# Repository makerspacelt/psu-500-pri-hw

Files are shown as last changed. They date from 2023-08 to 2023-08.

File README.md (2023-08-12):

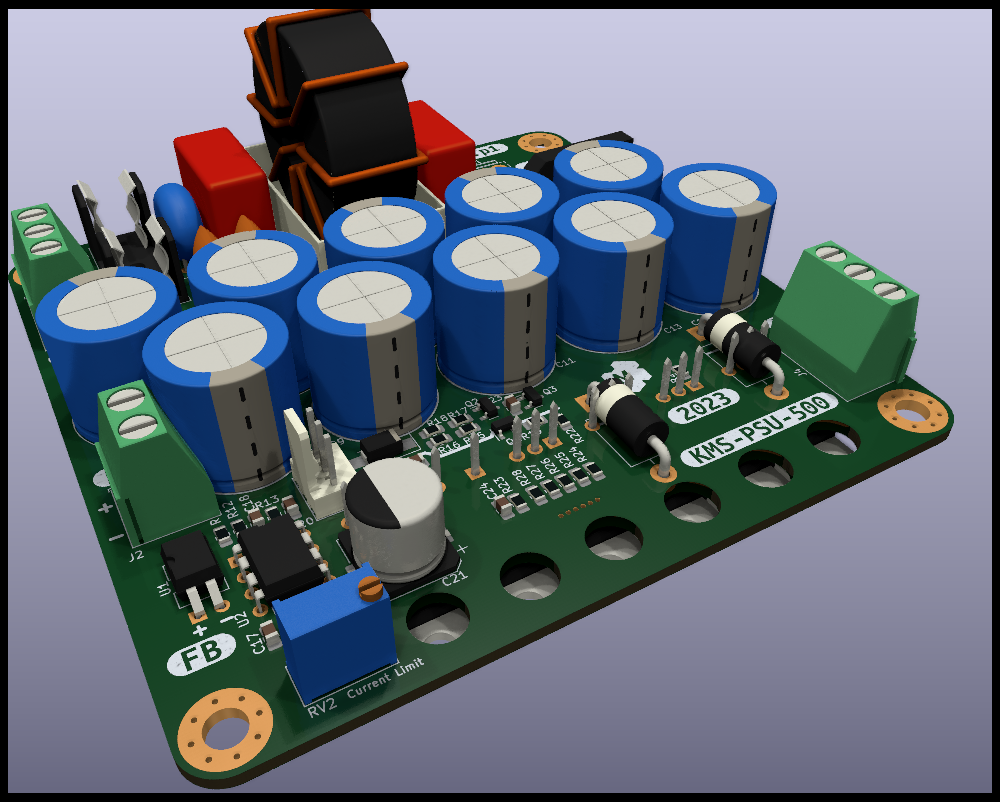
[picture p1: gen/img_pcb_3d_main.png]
PCB 3d main


This is atempt to design a 500W PSU primary side 

Dev NOTE: before commit, run `./kibot.sh` to regenerate documentation, gerbers and other assets.

* [schematics.pdf](gen/schematics.pdf)
* [pcb.pdf with dimensions](gen/pcb.pdf)

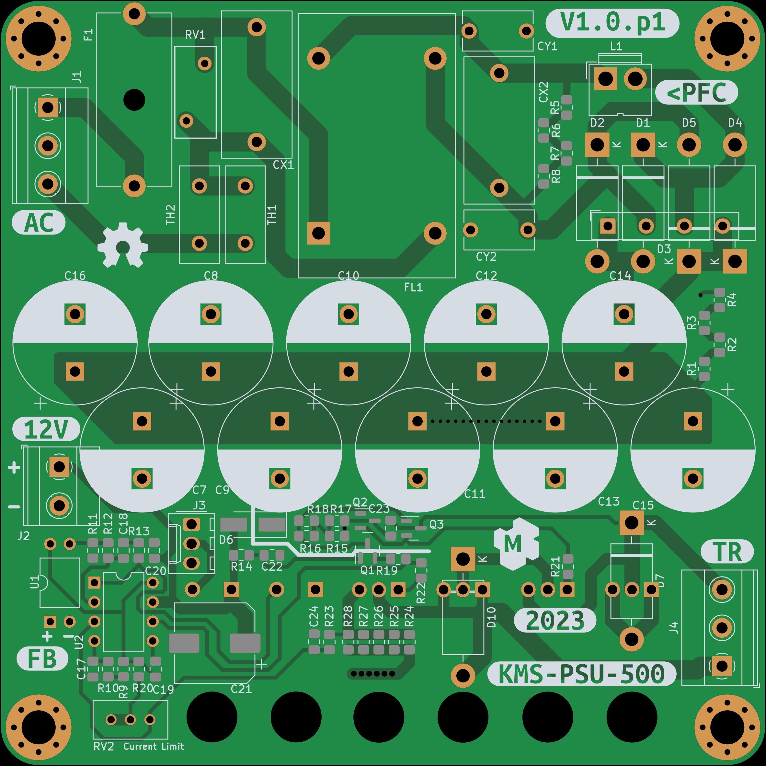
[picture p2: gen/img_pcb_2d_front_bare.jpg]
PCB 2d front bare

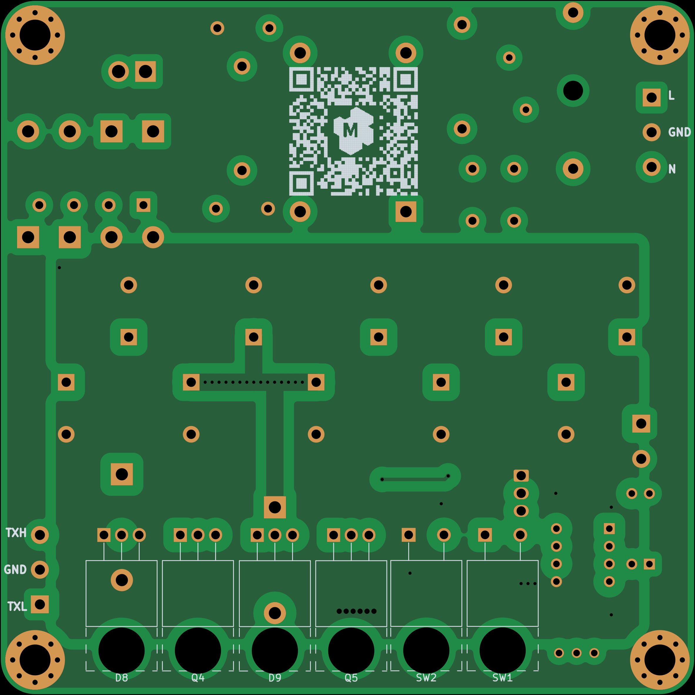
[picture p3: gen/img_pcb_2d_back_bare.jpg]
PCB 2d back bare


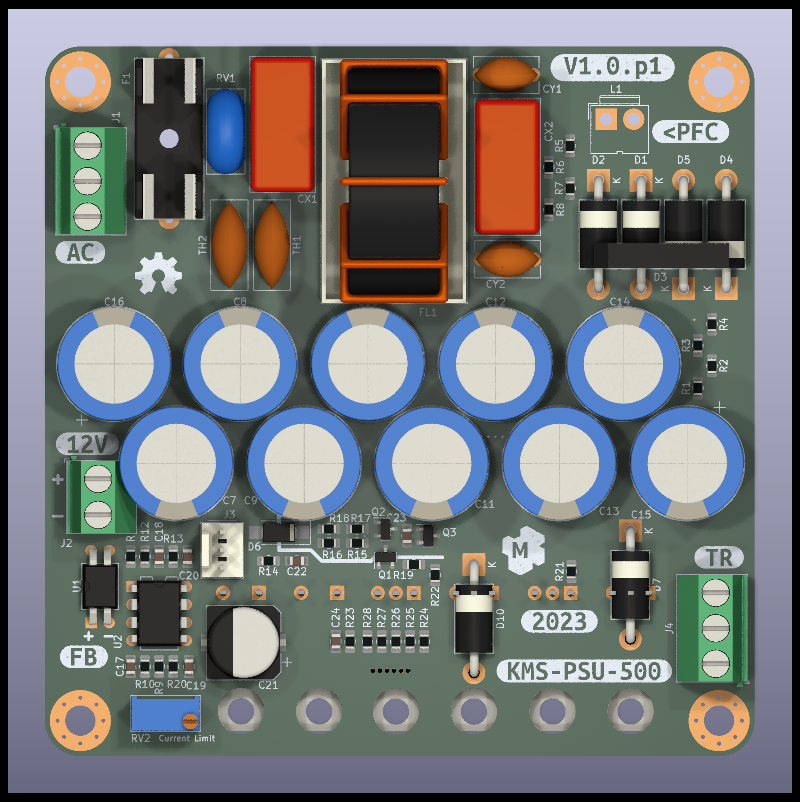
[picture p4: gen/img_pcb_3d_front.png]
PCB 3d front


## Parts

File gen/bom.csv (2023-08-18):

Row | Description | Part | References | Value | Footprint | Quantity Per PCB | Status | Datasheet | jlc-part-type | LCSC# | Value2
1 | Unpolarized capacitor | C | C24 | 100p | C_0805_2012Metric_Pad1.18x1.45mm_HandSolder | 1 |  | ~
2 | Unpolarized capacitor | C | C17 | 1n | C_0805_2012Metric_Pad1.18x1.45mm_HandSolder | 1 |  | ~
3 | Unpolarized capacitor | C | C18 | 10n | C_0805_2012Metric_Pad1.18x1.45mm_HandSolder | 1 |  | ~
4 | Unpolarized capacitor | C | C20,C22 | 100n | C_0805_2012Metric_Pad1.18x1.45mm_HandSolder | 2 |  | ~
5 | Unpolarized capacitor | C | C23 | 1u | C_0805_2012Metric_Pad1.18x1.45mm_HandSolder | 1 |  | ~ |  |  | 16V
6 | Unpolarized capacitor | C | C19 | 10u | C_0805_2012Metric_Pad1.18x1.45mm_HandSolder | 1 |  | ~ |  |  | 10v
7 | Polarized capacitor | C_Polarized | C7,C8,C9,C10,C11,C12,C13,C14,C15,C16 | 47u | CP_Radial_D16.0mm_P7.50mm | 10 |  | ~ |  |  | 400v
8 | Polarized capacitor | C_Polarized | C21 | 100u | CP_Elec_10x10 | 1 |  | ~ |  |  | 16v
9 | Polarized capacitor | C_Polarized | C1,C2 | 220u | CP_Radial_D30.0mm_P10.00mm_SnapIn | 2 |  | ~ |  |  | 400v
10 | Polarized capacitor | C_Polarized | C3,C4,C5,C6 | 470u | CP_Radial_D24.0mm_P10.00mm_SnapIn | 4 |  | ~ |  |  | 200v
11 | Unpolarized capacitor | C | CX1,CX2 | 470n | C_Rect_L19.0mm_W9.0mm_P15.00mm_MKS4 | 2 |  | https://datasheet.lcsc.com/lcsc/C5454415.pdf |  | C5454415 | 250V~
12 | Unpolarized capacitor | C | CY1,CY2 | 2n2 | C_Disc_D9.0mm_W5.0mm_P7.50mm | 2 |  | https://datasheet.lcsc.com/lcsc/C5355118.pdf |  | C5355118 | 250V~
13 | Silicon Bridge Rectifier, 40V Vrms, 1.5A If, pins=-AA+, SIL-package | B40C2300-1500A | D3 | GBU1010 | Diode_Bridge_19.0x3.5x10.0mm_P5.0mm | 1 |  | https://datasheet.lcsc.com/lcsc/2208121800_SEP-GBU1010_C5127096.pdf |  | C5127096
14 | Dual diode, common anode on pin 1 | D_Dual_CommonCathode_AKA_Parallel | D8,D9 | MURF1040GCT | TO-220-3_Horizontal_TabUp | 2 |  | https://datasheet.lcsc.com/lcsc/2205111516_DIYI-Elec-Tech-MURF1040GCT-H_C2995510.pdf |  | C2995510
15 | 1000V 3A Soft Recovery Ultrafast Rectifier Diode, DO-201AD | UF5408 | D6 | S2M | D_SMA_Handsoldering | 1 |  | https://datasheet.lcsc.com/lcsc/1811101212_Shandong-Jingdao-Microelectronics-S2M_C116114.pdf |  |  | 400V
16 | 1000V 3A General Purpose Rectifier Diode, DO-201AD | 1N5408 | D7,D10 | UF5408 | D_DO-201AD_P15.24mm_Horizontal | 2 |  | https://datasheet.lcsc.com/lcsc/1912111437_SUNMATE-Elec-UF5408_C424502.pdf
17 | 1000V 3A General Purpose Rectifier Diode, DO-201AD | 1N5408 | D1,D2,D4,D5 | ~ | D_DO-201AD_P15.24mm_Horizontal | 4 |  | ~
18 | Fuse | Fuse | F1 | 5A | Fuseholder_Cylinder-5x20mm_Schurter_0031_8201_Horizontal_Open | 1 |  | https://datasheet.lcsc.com/lcsc/C717030.pdf |  | C717030
19 | EMI 2-inductor common mode filter | Filter_EMI_CommonMode | FL1 | EMI | L_CommonMode_Toroid_Vertical_L34.3mm_W20.3mm_Px15.24mm_Py22.86mm_Bourns_8100 | 1 |  | https://datasheet.lcsc.com/lcsc/2201121530_PROD-Tech-PDUUAT105-202MLN_C2932158.pdf |  | C2932158
20 | Generic screw terminal, single row, 01x02, script generated (kicad-library-utils/schlib/autogen/connector/) | Screw_Terminal_01x02 | J2 | 12V | TerminalBlock_Phoenix_MKDS-1,5-2-5.08_1x02_P5.08mm_Horizontal | 1 |  | ~
21 | Generic screw terminal, single row, 01x03, script generated (kicad-library-utils/schlib/autogen/connector/) | Screw_Terminal_01x03 | J1,J4 | AC | TerminalBlock_Phoenix_MKDS-1,5-3_1x03_P5.00mm_Horizontal | 2 |  | ~
22 | Generic connector, single row, 01x03, script generated (kicad-library-utils/schlib/autogen/connector/) | Conn_01x03 | J3 | FAN | Molex_KK-254_AE-6410-03A_1x03_P2.54mm_Vertical | 1 |  | ~
23 | Inductor with iron core | L_Iron | L1 | PFC | JWT_A3963_1x02_P3.96mm_Vertical | 1 |  | ~
24 | Compact AC/DC board mount power module 3W 5V | HLK-PM01 | PS1 | PSU 12V 1A | Converter_ACDC_HiLink_HLK-PMxx | 1 |  | http://www.hlktech.net/product_detail.php?ProId=54
25 | NPN transistor, base/emitter/collector | Q_NPN_BEC | Q1 | 13001 | SOT-23 | 1 |  | https://datasheet.lcsc.com/lcsc/2212161630_HXY-MOSFET-13001_C5261071.pdf |  | C5261071 | 400V
26 | 10A Id, 400V Vds, N-Channel Power MOSFET, 500mOhm Rds, TO-220AB | IRF740 | Q4,Q5 | IRF740 | TO-220-3_Horizontal_TabUp | 2 |  | https://datasheet.lcsc.com/lcsc/2203231030_Minos-IRF740_C2980280.pdf |  | C2980280
27 | NPN transistor, base/emitter/collector | Q_NPN_BEC | Q2 | S8050 | SOT-23 | 1 |  | https://datasheet.lcsc.com/lcsc/2304140030_Jiangsu-Changjing-Electronics-Technology-Co---Ltd--S8050_C105433.pdf
28 | PNP transistor, base/emitter/collector | Q_PNP_BEC | Q3 | S8550 | SOT-23 | 1 |  | https://datasheet.lcsc.com/lcsc/2205061000_Guangdong-Hottech-S8550_C181159.pdf
29 | Resistor | R | R24,R25,R26,R27,R28 | 0R1 | R_0805_2012Metric_Pad1.20x1.40mm_HandSolder | 5 |  | ~
30 | Resistor | R | R19,R21,R22 | 10 | R_0805_2012Metric_Pad1.20x1.40mm_HandSolder | 3 |  | ~
31 | Resistor | R | R11,R15,R16,R17,R18,R23 | 1k | R_0805_2012Metric_Pad1.20x1.40mm_HandSolder | 6 |  | ~
32 | Resistor | R | R10 | 2k2 | R_0805_2012Metric_Pad1.20x1.40mm_HandSolder | 1 |  | ~
33 | Resistor | R | R12,R20 | 4k7 | R_0805_2012Metric_Pad1.20x1.40mm_HandSolder | 2 |  | ~
34 | Resistor | R | R13,R14 | 10k | R_0805_2012Metric_Pad1.20x1.40mm_HandSolder | 2 |  | ~
35 | Resistor | R | R9 | 15k | R_0805_2012Metric_Pad1.20x1.40mm_HandSolder | 1 |  | ~
36 | Resistor | R | R1,R2,R3,R4,R5,R6,R7,R8 | 220k | R_0805_2012Metric_Pad1.20x1.40mm_HandSolder | 8 |  | ~
37 | Trim-potentiometer | R_Potentiometer_Trim | RV2 | 4k7 | Potentiometer_Bourns_3296W_Vertical | 1 |  | ~
38 | Voltage dependent resistor | Varistor | RV1 | 10D431K | RV_Disc_D12mm_W5.4mm_P7.5mm | 1 |  | https://datasheet.lcsc.com/lcsc/2304140030_COV-10D431K_C317794.pdf |  | C317794
39 | Single Pole Single Throw (SPST) switch, temperature dependent | SW_SPST_Temperature | SW1 | 50C NC | TO-220-2_Horizontal_TabUp | 1 |  | ~
40 | Single Pole Single Throw (SPST) switch, temperature dependent | SW_SPST_Temperature | SW2 | 85C | TO-220-2_Horizontal_TabUp | 1 |  | ~
41 | Flash symbol, small | SYM_Flash_Small | SYM1 | SYM_Flash_Small | qr | 1 |  | ~
42 | Temperature dependent resistor, negative temperature coefficient | Thermistor_NTC | TH1,TH2 | 5D-15 | C_Disc_D12.5mm_W5.0mm_P7.50mm | 2 |  | https://datasheet.lcsc.com/lcsc/C2839620.pdf |  | C2839620
43 | DC Optocoupler, Vce 35V, CTR 50%, DIP-4 | LTV-817M | U1 | LTV-817M | DIP-4_W10.16mm | 1 |  | http://www.us.liteon.com/downloads/LTV-817-827-847.PDF |  | C109226
44 | Current-Mode PWM Controllers, 50% Duty Cycle, 8.4V/7.6V UVLO, PDIP-8 | UC3845_DIP8 | U2 | UC3845B | DIP-8_W7.62mm | 1 |  | https://datasheet.lcsc.com/lcsc/2007031829_UMW-Youtai-Semiconductor-Co---Ltd--UC3845B_C347460.pdf |  | C347460

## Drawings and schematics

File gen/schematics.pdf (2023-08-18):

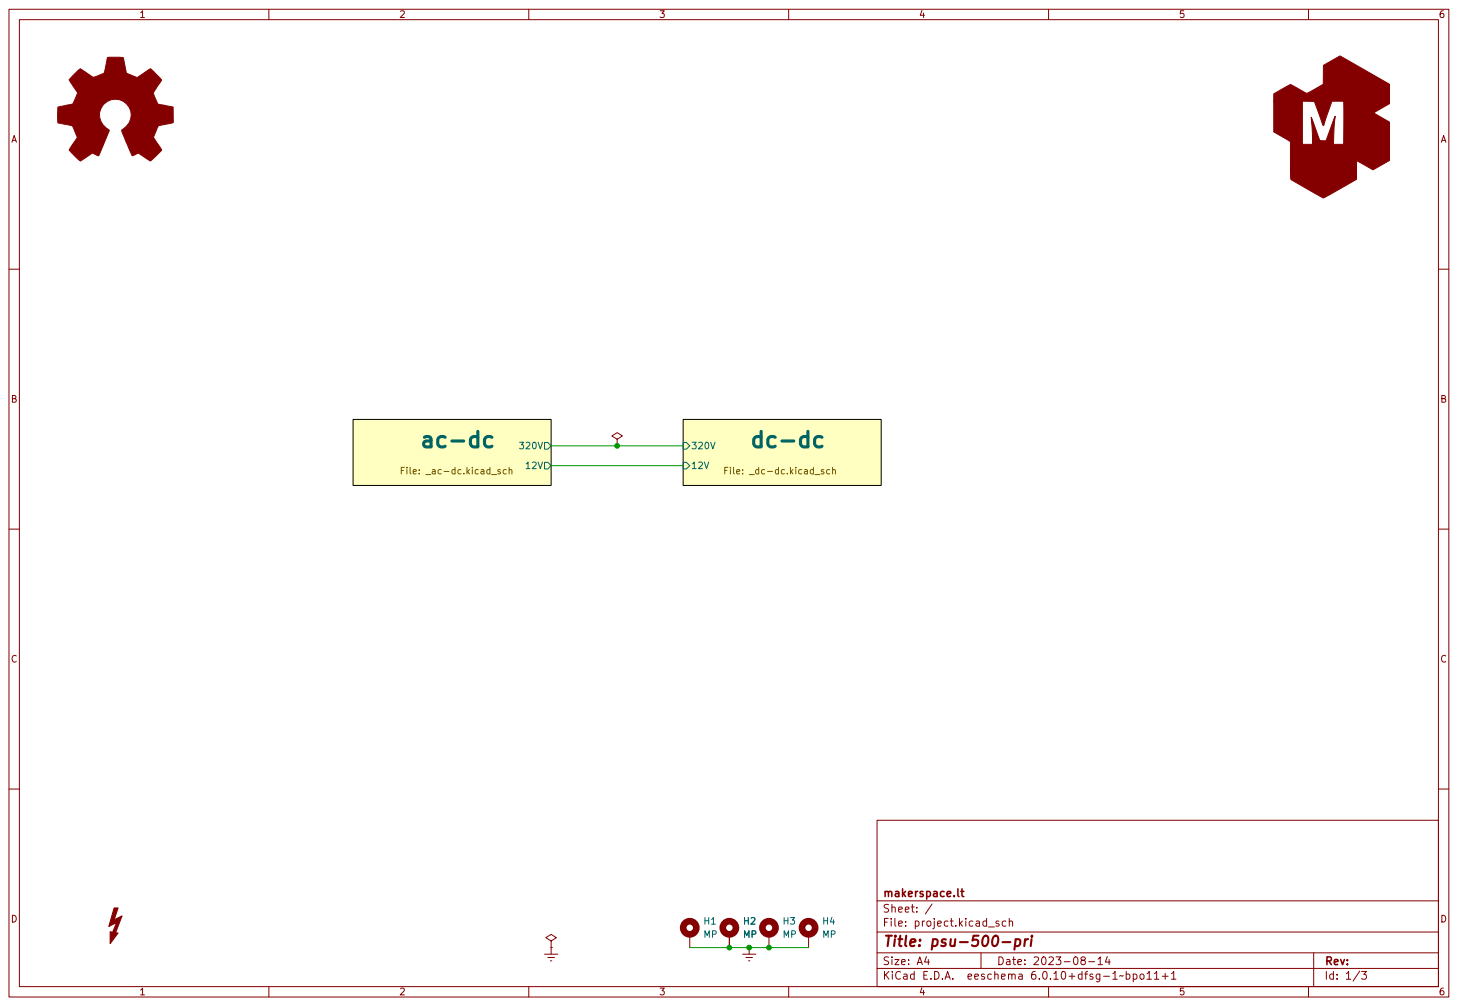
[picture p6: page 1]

File: project.kicad_sch Sheet: / makerspace.lt

Id: 1/3 Title: psu-500-pri

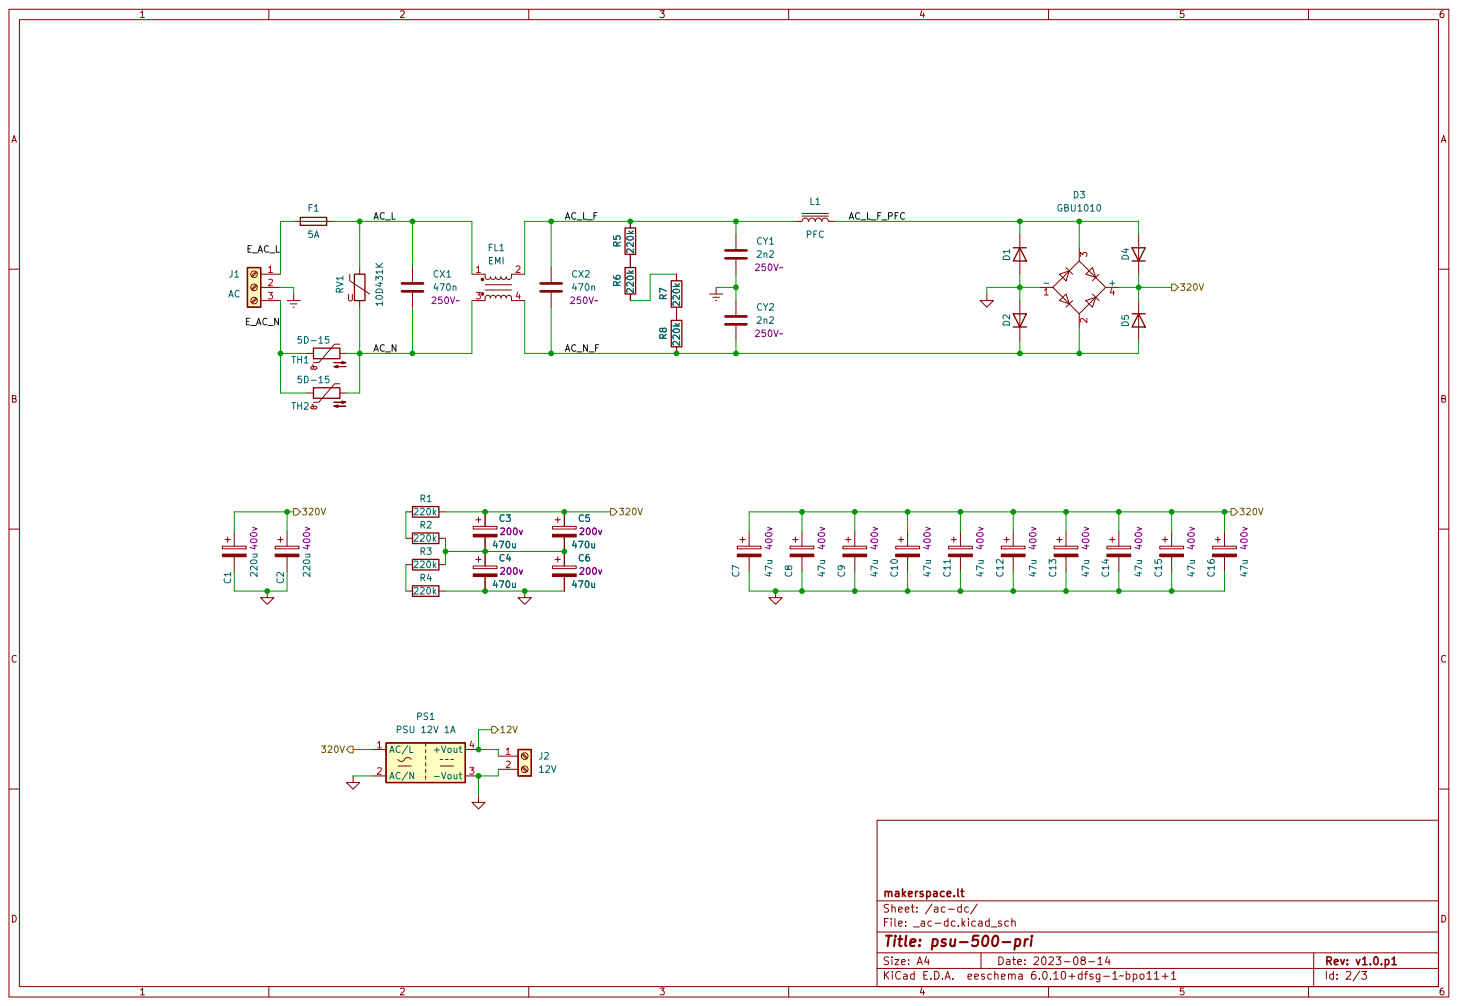
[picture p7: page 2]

File: _ac-dc.kicad_sch Sheet: /ac-dc/ makerspace.lt R1

Id: 2/3 Title: psu-500-pri

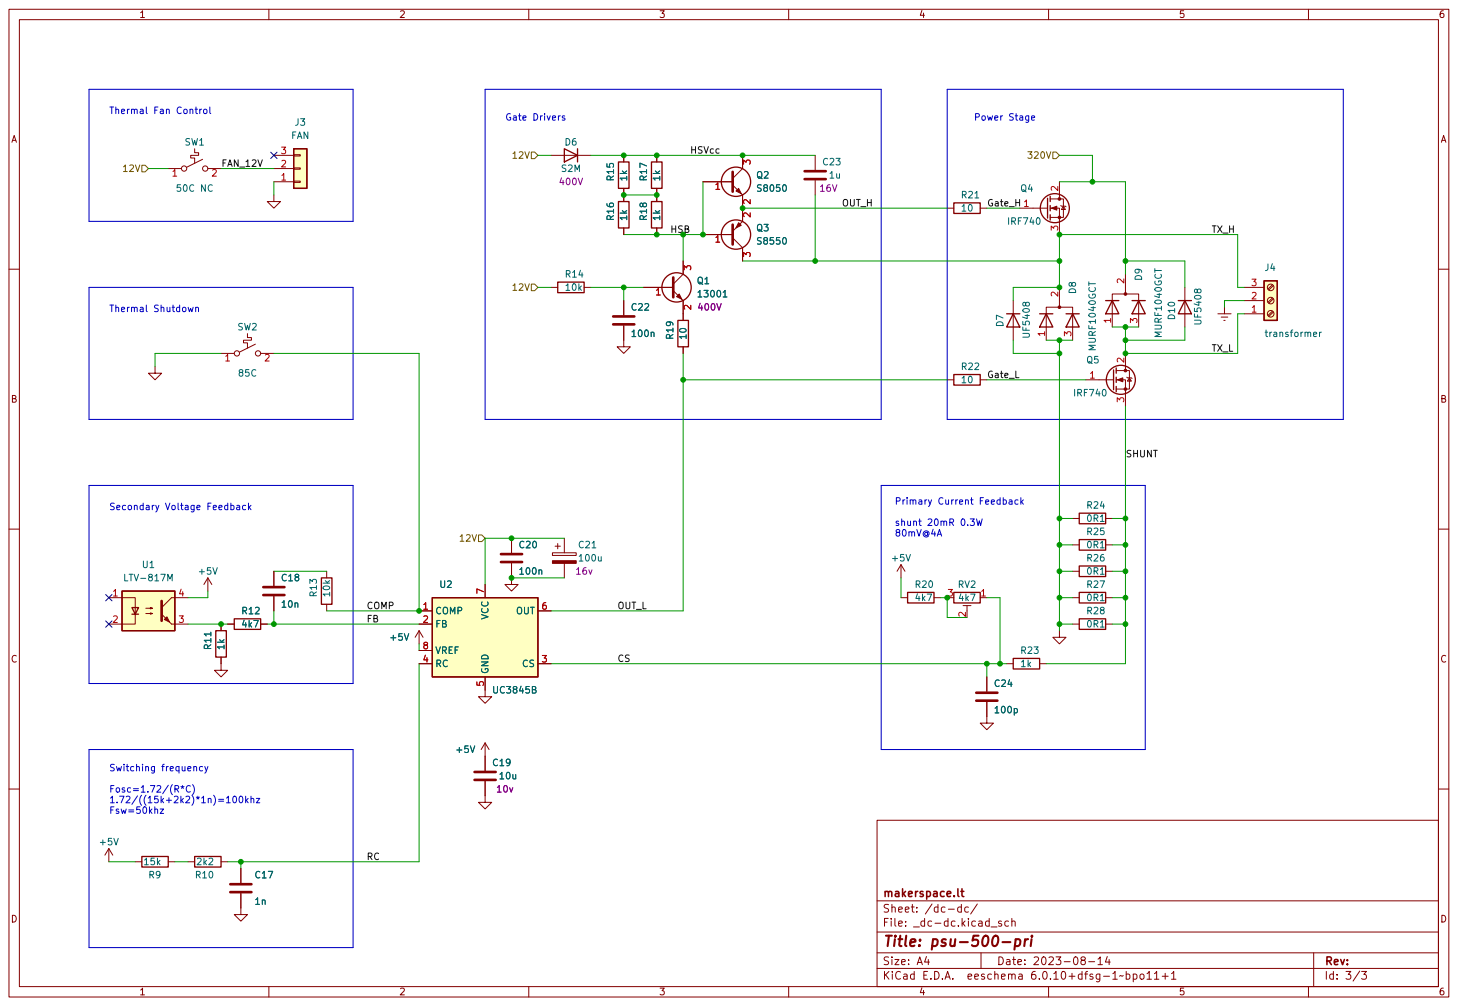
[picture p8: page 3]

File: _dc-dc.kicad_sch Sheet: /dc-dc/ makerspace.lt

Id: 3/3 Title: psu-500-pri

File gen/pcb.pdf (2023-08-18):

100 mm

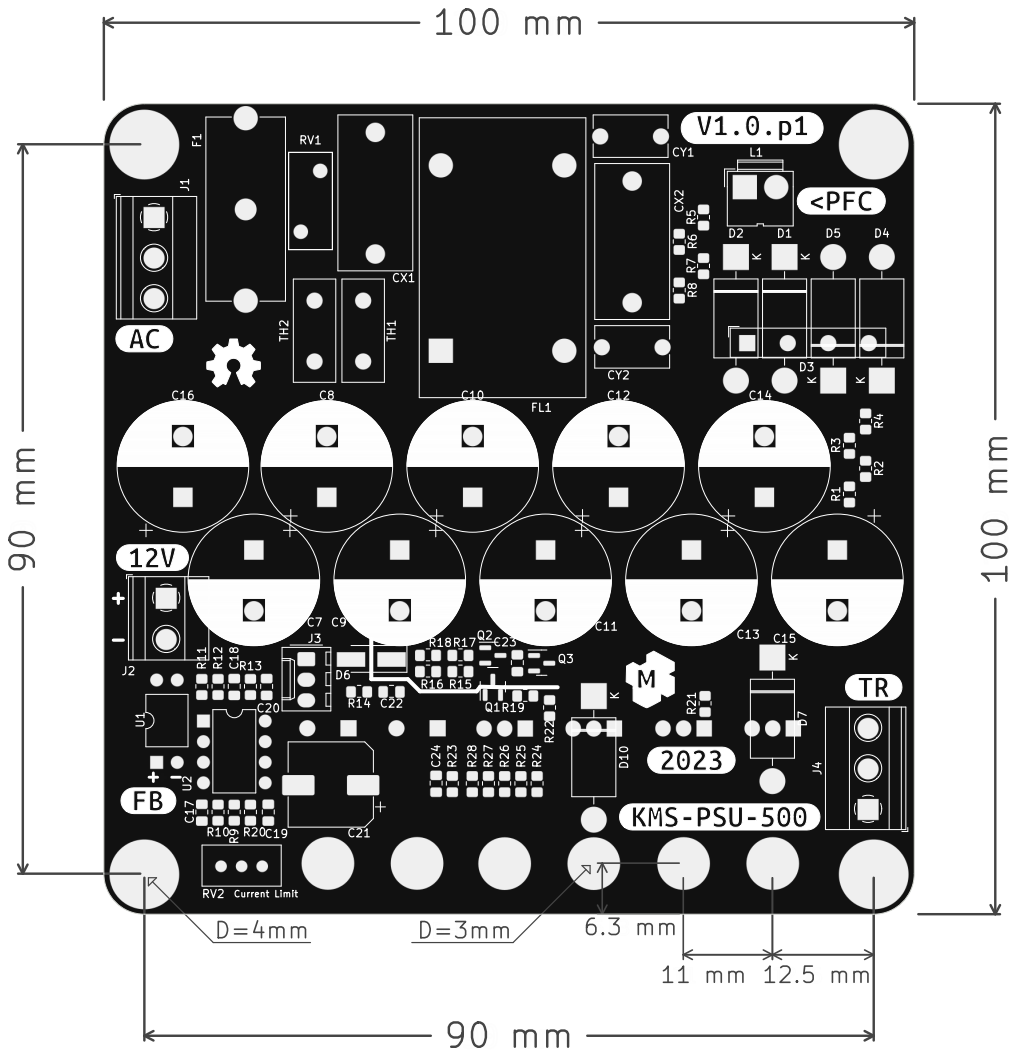
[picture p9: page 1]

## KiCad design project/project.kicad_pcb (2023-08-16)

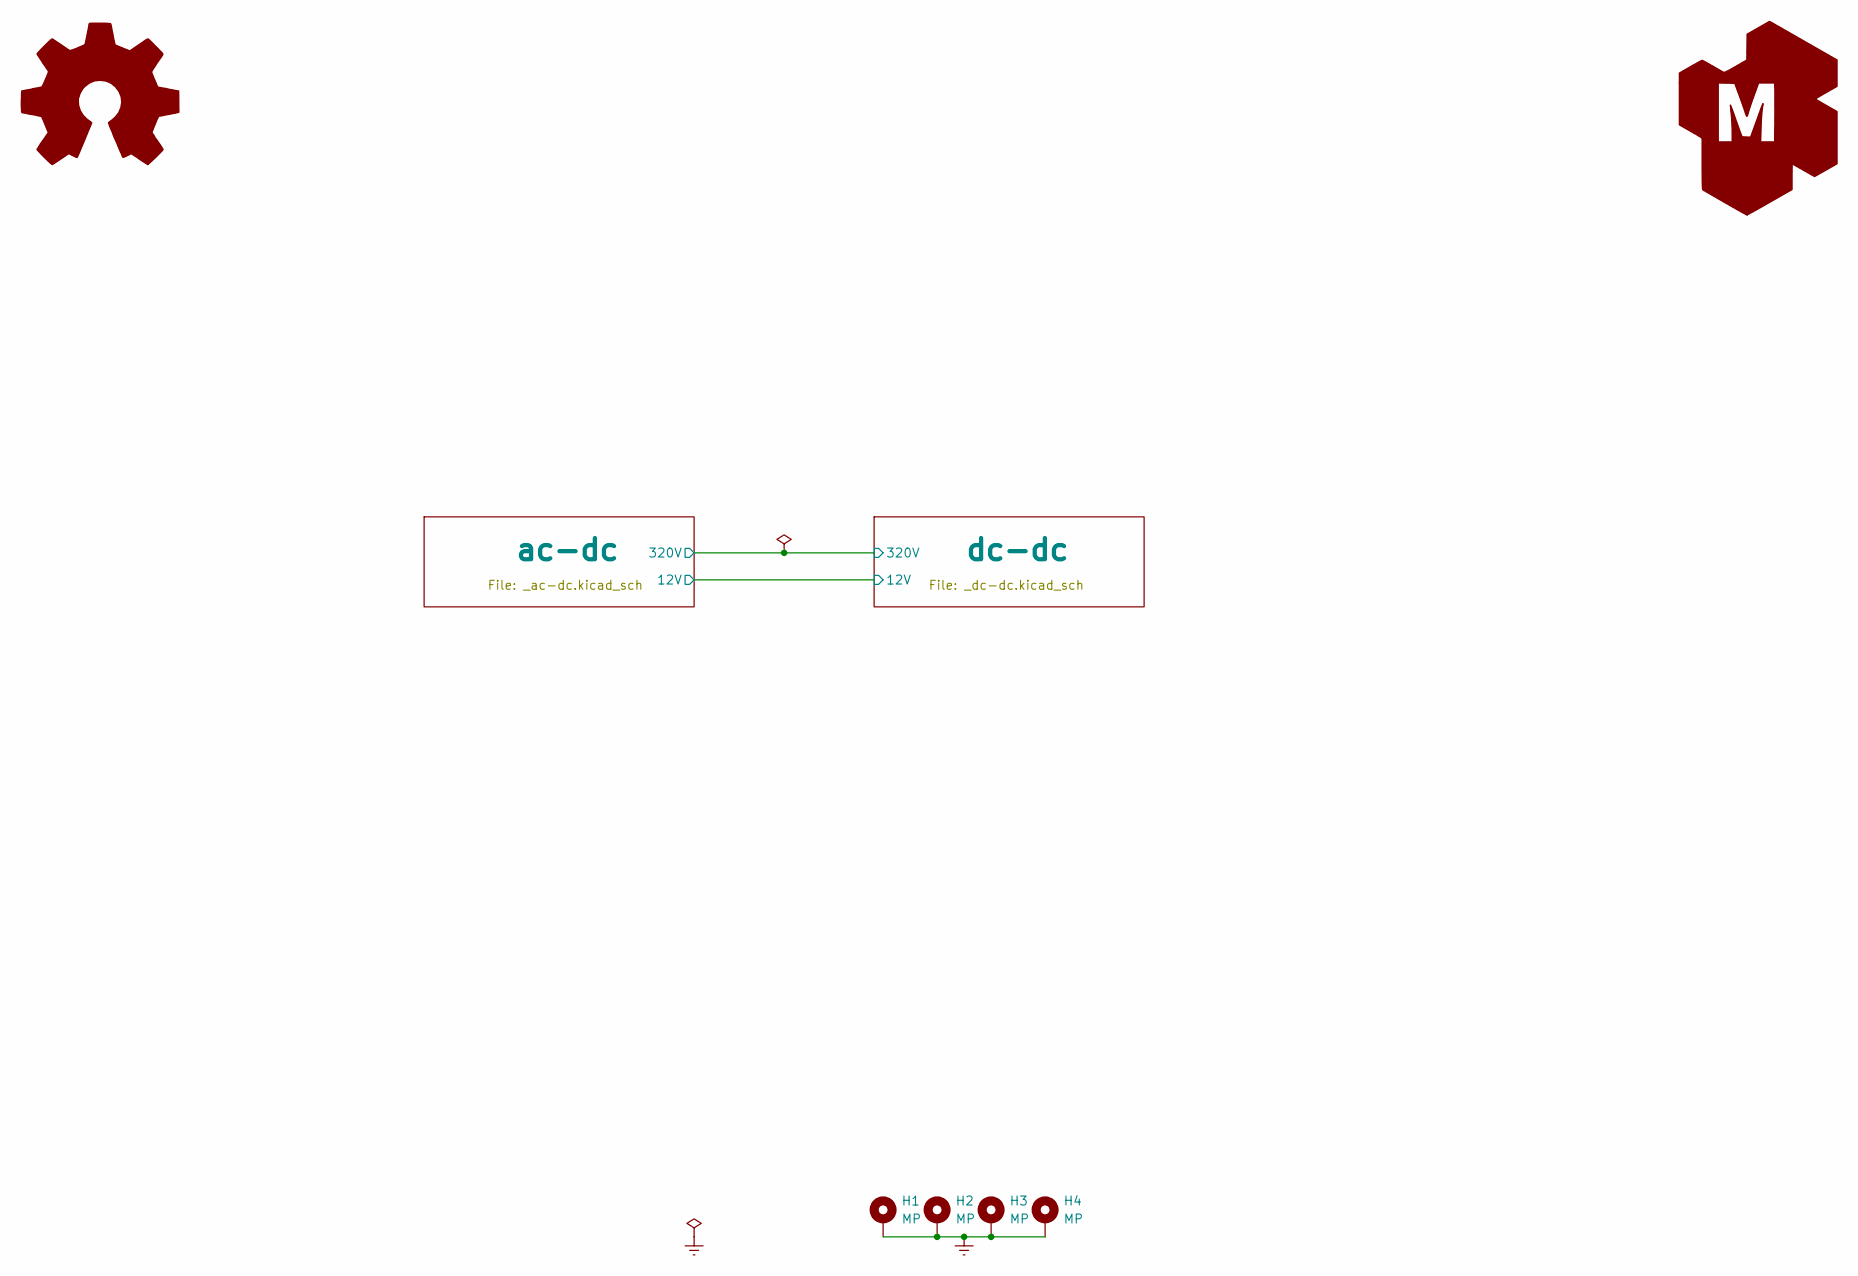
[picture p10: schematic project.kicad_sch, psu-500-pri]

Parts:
G1: Logo_Open_Hardware_Large; OSHW-Symbol_6.7x6mm_SilkScreen
G2: LOGO_KMS; logo_kms_small_silkscreen
H1, H2, H3, H4: MP; MountingHole_4.3mm_M4_Pad_Via

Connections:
Earth: H1.1, H2.1, H3.1, H4.1; also elsewhere on the board

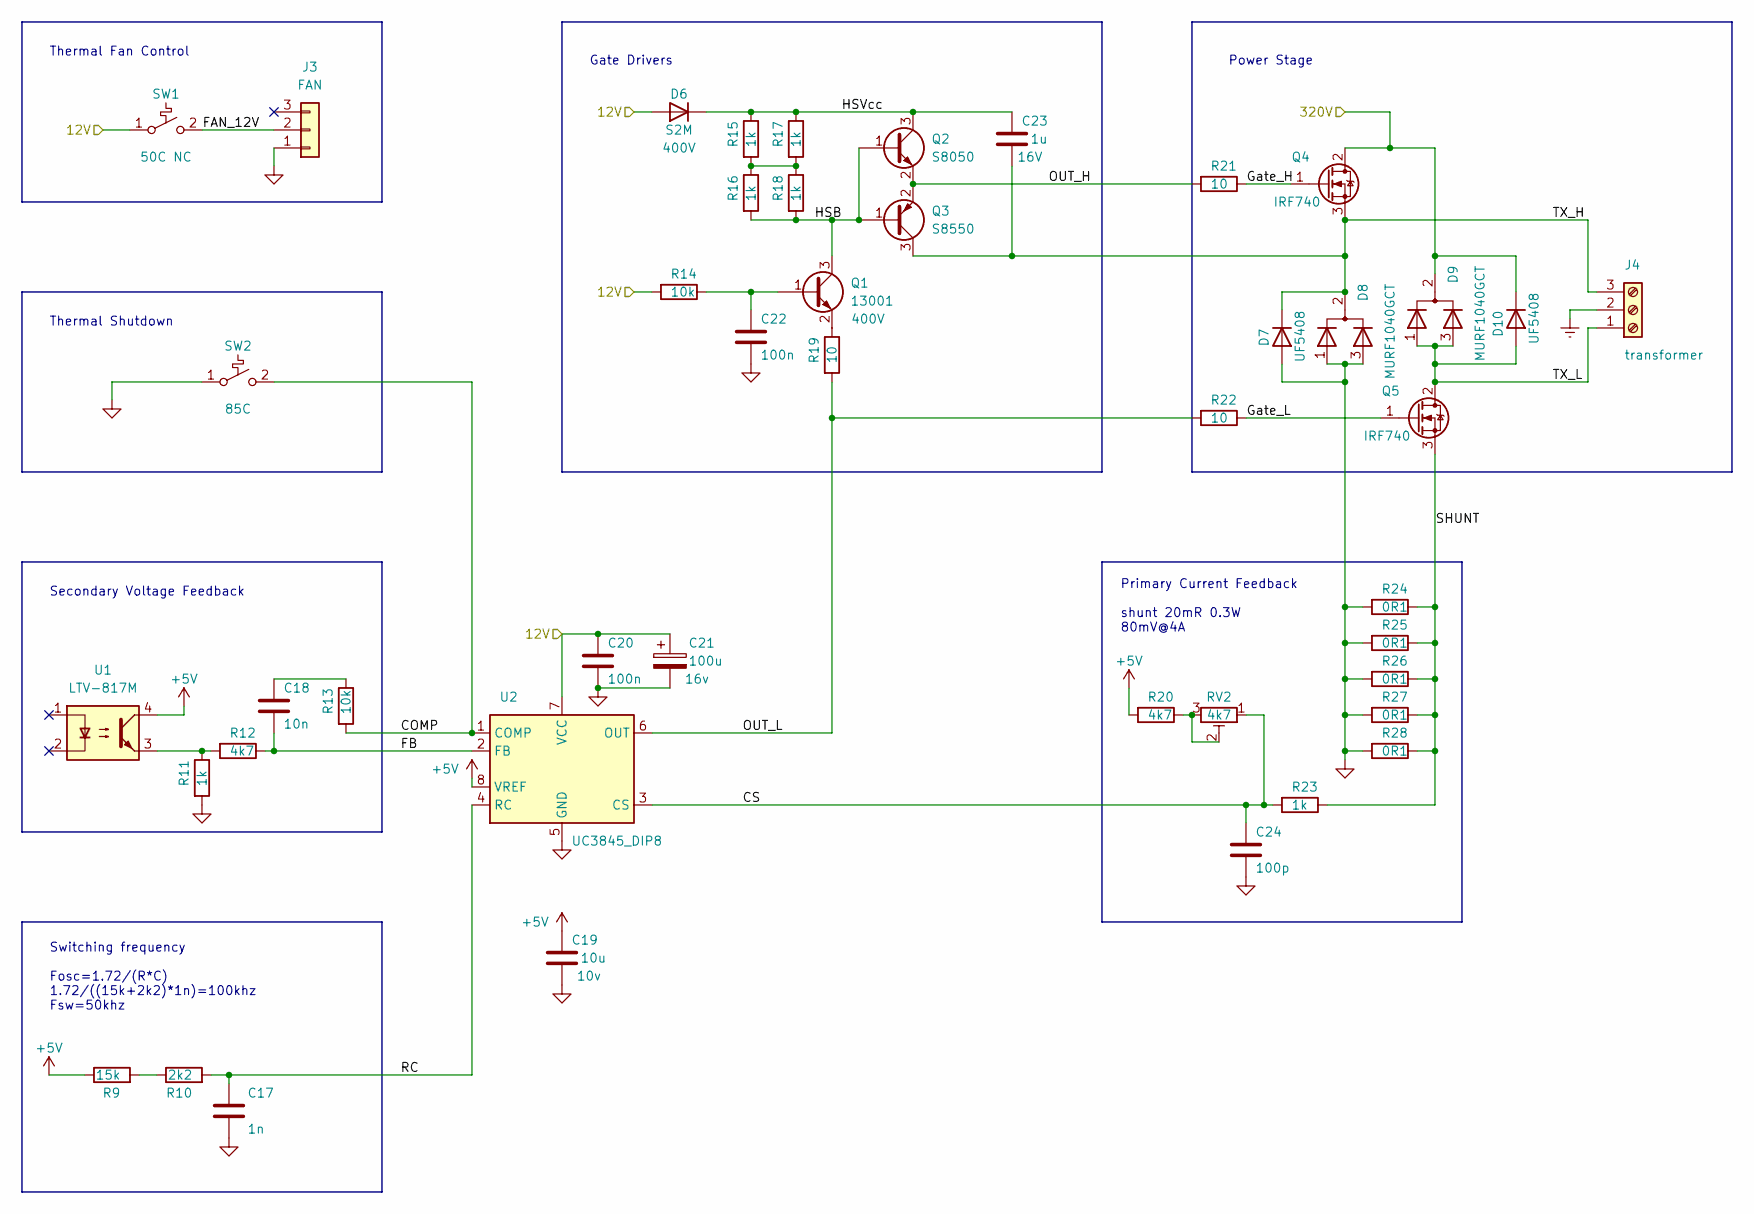
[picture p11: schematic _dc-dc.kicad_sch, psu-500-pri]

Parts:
C17: 1n; C_0805_2012Metric_Pad1.18x1.45mm_HandSolder
C18: 10n; C_0805_2012Metric_Pad1.18x1.45mm_HandSolder
C19: 10u; C_0805_2012Metric_Pad1.18x1.45mm_HandSolder
C20, C22: 100n; C_0805_2012Metric_Pad1.18x1.45mm_HandSolder
C21: 100u; CP_Elec_10x10
C23: 1u; C_0805_2012Metric_Pad1.18x1.45mm_HandSolder
C24: 100p; C_0805_2012Metric_Pad1.18x1.45mm_HandSolder
D6: S2M; D_SMA_Handsoldering
D7, D10: UF5408; D_DO-201AD_P15.24mm_Horizontal
D8, D9: MURF1040GCT; TO-220-3_Horizontal_TabUp; LCSC# C2995510
J3: FAN; Molex_KK-254_AE-6410-03A_1x03_P2.54mm_Vertical
J4: transformer; TerminalBlock_Phoenix_MKDS-1,5-3_1x03_P5.00mm_Horizontal
Q1: 13001; SOT-23; LCSC# C5261071
Q2: S8050; SOT-23
Q3: S8550; SOT-23
Q4, Q5: IRF740; TO-220-3_Horizontal_TabUp
R9: 15k; R_0805_2012Metric_Pad1.20x1.40mm_HandSolder
R10: 2k2; R_0805_2012Metric_Pad1.20x1.40mm_HandSolder
R11, R15, R16, R17, R18, R23: 1k; R_0805_2012Metric_Pad1.20x1.40mm_HandSolder
R12, R20: 4k7; R_0805_2012Metric_Pad1.20x1.40mm_HandSolder
R13, R14: 10k; R_0805_2012Metric_Pad1.20x1.40mm_HandSolder
R19, R21, R22: 10; R_0805_2012Metric_Pad1.20x1.40mm_HandSolder
R24, R25, R26, R27, R28: 0R1; R_0805_2012Metric_Pad1.20x1.40mm_HandSolder
RV2: 4k7; Potentiometer_Bourns_3296W_Vertical
SW1: 50C NC; TO-220-2_Horizontal_TabUp
SW2: 85C; TO-220-2_Horizontal_TabUp
U1: LTV-817M; DIP-4_W10.16mm; LCSC# C109226
U2: UC3845_DIP8; DIP-8_W7.62mm

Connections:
+5V: C19.1, R9.1, R20.2, U1.4, U2.8 (VREF)
/ac-dc/12V: C20.1, C21.1, D6.2 (A), R14.2, SW1.1 (A), U2.7 (VCC); also elsewhere on the board
/ac-dc/320V: D9.2 (A), D10.1 (K), Q4.2 (D); also elsewhere on the board
/dc-dc/COMP: R13.2, SW2.2 (B), U2.1 (COMP)
/dc-dc/CS: C24.1, R23.2, RV2.1, U2.3 (CS)
/dc-dc/FAN_12V: J3.2, SW1.2 (B)
/dc-dc/FB: C18.2, R12.1, U2.2 (FB)
/dc-dc/Gate_H: Q4.1 (G), R21.1
/dc-dc/Gate_L: Q5.1 (G), R22.1
/dc-dc/HSB: Q1.3 (C), Q2.1 (B), Q3.1 (B), R16.2, R18.2
/dc-dc/HSVcc: C23.1, D6.1 (K), Q2.3 (C), R15.1, R17.1
/dc-dc/OUT_H: Q2.2 (E), Q3.2 (E), R21.2
/dc-dc/OUT_L: R19.2, R22.2, U2.6 (OUT)
/dc-dc/RC: C17.1, R10.2, U2.4 (RC)
/dc-dc/SHUNT: Q5.3 (S), R23.1, R24.1, R25.1, R26.1, R27.1, R28.1
/dc-dc/TX_H: C23.2, D7.1 (K), D8.2 (A), J4.3, Q3.3 (C), Q4.3 (S)
/dc-dc/TX_L: D9.1 (K), D9.3 (K), D10.2 (A), J4.1, Q5.2 (D)
Earth: J4.2; also elsewhere on the board
GND: C17.2, C19.2, C20.2, C21.2, C22.2, C24.2, D7.2 (A), D8.1 (K), D8.3 (K), J3.1, R11.2, R24.2, R25.2, R26.2, R27.2, R28.2, SW2.1 (A), U2.5 (GND); also elsewhere on the board
unnamed: C18.1, R13.1
unnamed: C22.1, Q1.1 (B), R14.1
unnamed: Q1.2 (E), R19.1
unnamed: R9.2, R10.1
unnamed: R11.1, R12.2, U1.3
unnamed: R15.2, R16.1, R17.2, R18.1
unnamed: R20.1, RV2.2, RV2.3

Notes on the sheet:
Switching frequency Fosc=1.72/(R*C) 1.72/((15k+2k2)*1n)=100khz Fsw=50khz
Primary Current Feedback shunt 20mR 0.3W 80mV@4A
Gate Drivers
Thermal Fan Control
Thermal Shutdown
Secondary Voltage Feedback
Power Stage

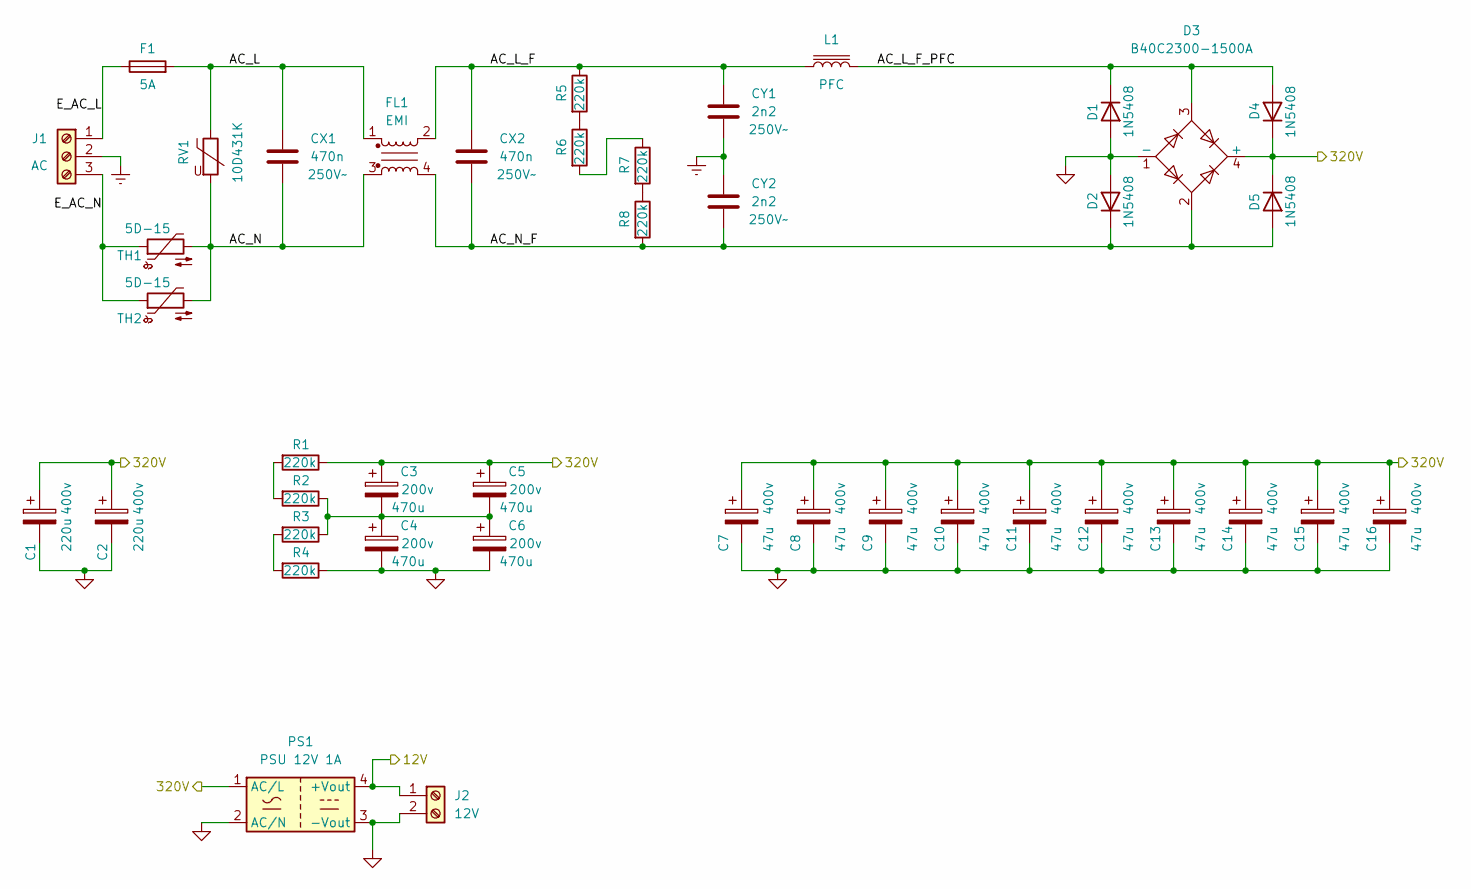
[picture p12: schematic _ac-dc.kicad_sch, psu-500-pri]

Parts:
C1, C2: 220u; CP_Radial_D30.0mm_P10.00mm_SnapIn
C3, C4, C5, C6: 470u; CP_Radial_D24.0mm_P10.00mm_SnapIn
C7, C8, C9, C10, C11, C12, C13, C14, C15, C16: 47u; CP_Radial_D16.0mm_P7.50mm
CX1, CX2: 470n; C_Rect_L19.0mm_W9.0mm_P15.00mm_MKS4
CY1, CY2: 2n2; C_Disc_D9.0mm_W5.0mm_P7.50mm
D1, D2, D4, D5: 1N5408; D_DO-201AD_P15.24mm_Horizontal
D3: B40C2300-1500A; Diode_Bridge_19.0x3.5x10.0mm_P5.0mm
F1: 5A; Fuseholder_Cylinder-5x20mm_Schurter_0031_8201_Horizontal_Op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
FL1: EMI; L_CommonMode_Toroid_Vertical_L34.3mm_W20.3mm_Px15.24mm_Py22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
J1: AC; TerminalBlock_Phoenix_MKDS-1,5-3_1x03_P5.00mm_Horizontal
J2: 12V; TerminalBlock_Phoenix_MKDS-1,5-2-5.08_1x02_P5.08mm_Horizont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
L1: PFC; JWT_A3963_1x02_P3.96mm_Vertical
PS1: PSU 12V 1A; Converter_ACDC_HiLink_HLK-PMxx
R1, R2, R3, R4, R5, R6, R7, R8: 220k; R_0805_2012Metric_Pad1.20x1.40mm_HandSolder
RV1: 10D431K; RV_Disc_D12mm_W5.4mm_P7.5mm; LCSC# C317794
TH1, TH2: 5D-15; C_Disc_D12.5mm_W5.0mm_P7.50mm

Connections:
/ac-dc/12V: J2.1, PS1.4 (+Vout); also elsewhere on the board
/ac-dc/320V: C1.1, C2.1, C3.1, C5.1, C7.1, C8.1, C9.1, C10.1, C11.1, C12.1, C13.1, C14.1, C15.1, C16.1, D3.4 (+), D4.1 (K), D5.1 (K), PS1.1 (AC/L), R1.1; also elsewhere on the board
/ac-dc/AC_L: CX1.1, F1.2, FL1.1, RV1.1
/ac-dc/AC_L_F: CX2.1, CY1.1, FL1.2, L1.1, R5.1
/ac-dc/AC_L_F_PFC: D1.1 (K), D3.3, D4.2 (A), L1.2
/ac-dc/AC_N: CX1.2, FL1.3, RV1.2, TH1.2, TH2.2
/ac-dc/AC_N_F: CX2.2, CY2.2, D2.1 (K), D3.2, D5.2 (A), FL1.4, R8.2
/ac-dc/E_AC_L: F1.1, J1.1
/ac-dc/E_AC_N: J1.3, TH1.1, TH2.1
Earth: CY1.2, CY2.1, J1.2; also elsewhere on the board
GND: C1.2, C2.2, C4.2, C6.2, C7.2, C8.2, C9.2, C10.2, C11.2, C12.2, C13.2, C14.2, C15.2, C16.2, D1.2 (A), D2.2 (A), D3.1 (-), J2.2, PS1.2 (AC/N), PS1.3 (-Vout), R4.1; also elsewhere on the board
unnamed: C3.2, C4.1, C5.2, C6.1, R2.1, R3.1
unnamed: R1.2, R2.2
unnamed: R3.2, R4.2
unnamed: R5.2, R6.1
unnamed: R6.2, R7.1
unnamed: R7.2, R8.1

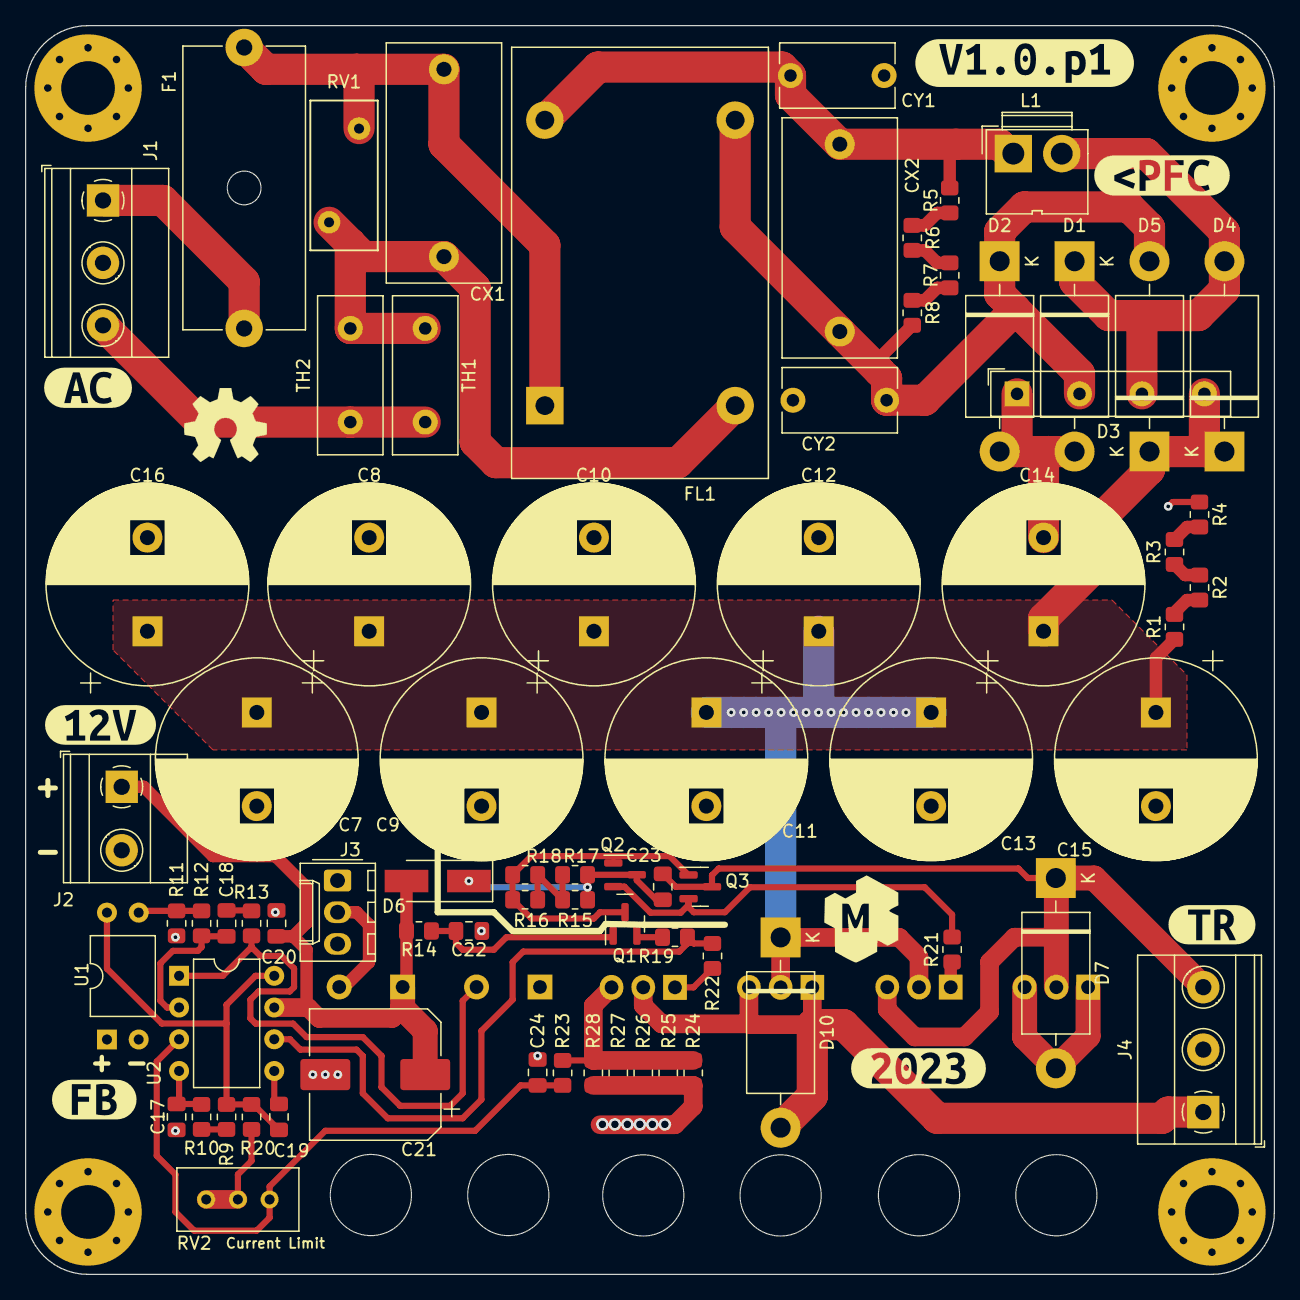
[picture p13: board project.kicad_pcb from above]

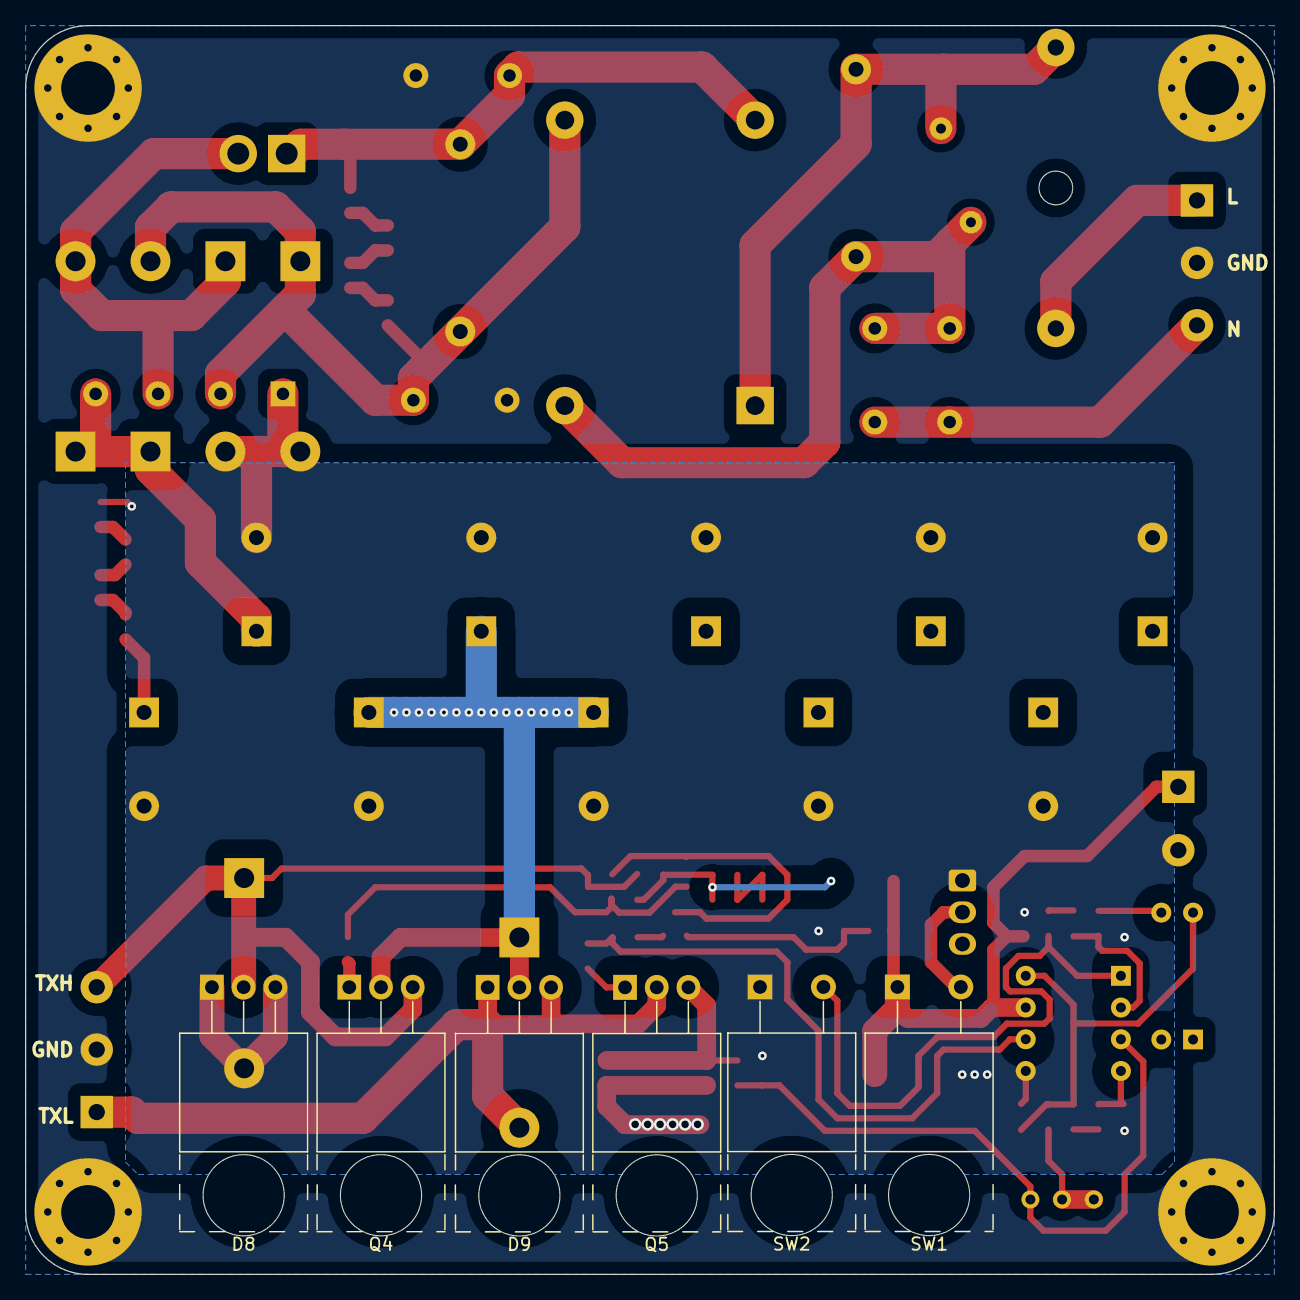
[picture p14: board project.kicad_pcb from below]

Board: 2 copper layers, 100.0 x 100.0 mm, 93 parts (6 on the bottom side), 39 nets.

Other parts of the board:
kibuzzard-64DA8E2C: G***; kibuzzard-64DA8E2C
kibuzzard-64DC9B3C: G***; kibuzzard-64DC9B3C
kibuzzard-64DC9B5D: G***; kibuzzard-64DC9B5D
kibuzzard-64DC9BC4: G***; kibuzzard-64DC9BC4
kibuzzard-64DC9C08: G***; kibuzzard-64DC9C08
kibuzzard-64DCA2D6: G***; kibuzzard-64DCA2D6
kibuzzard-64DCA30C: G***; kibuzzard-64DCA30C

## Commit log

2023-06-12 Add files via upload
    Kicad schematic files
    [gigapsu.kicad_pcb, gigapsu.kicad_sch]
2023-08-12 starting from square one
    [_ac-dc.kicad_sch, _dc-dc.kicad_sch, gigapsu.kicad_pcb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]
2023-08-12 adding more things and specifying components
    [_ac-dc.kicad_sch, _dc-dc.kicad_sch, project.kicad_sch]
2023-08-14 starting pcb
    [_ac-dc.kicad_sch, _dc-dc.kicad_sch, project.kicad_pcb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]
2023-08-16 finishing pcb
    [_ac-dc.kicad_sch, _dc-dc.kicad_sch, project.kicad_pcb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]
2023-08-16 small power traces rearrangement
    [project.kicad_pcb]
2023-08-18 finalizing pcb and adding gerbers
    [_bom.csv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]
2023-08-18 adding few part numbers to the bom
    [_ac-dc.kicad_sch, _dc-dc.kicad_sch, bom.csv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]
